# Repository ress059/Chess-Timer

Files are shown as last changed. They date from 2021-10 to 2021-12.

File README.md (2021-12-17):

# Chess-Timer

## Documentation
Bill of Materials, List of Requirements, and Behavioral Test Plans for quality testing.

## Firmware
In progress. Currently prototyping UI using Windows Simulator with LVGL library.

## PCB
Gerber files for manufacturing and PDFs of the board layout.

## Proof of Concept
Video and code to interface [these buttons](https://www.adafruit.com/product/3433) with an Arduino Uno.

## Schematic
PDF of the full schematic.

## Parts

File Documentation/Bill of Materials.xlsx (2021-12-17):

Chess Timer Parts List
 | USB, Programming Header, Battery Charger
 |  | Part | Designator | Part # | Digikey Part # | Quantity | Price Per | Total Price | Product URL (Digikey) | Notes
 | x | USB Mini B Connector | J1 | UX60SC-MB-5ST | UX60SC-MB-5ST-ND | 1 | $0.50 | $0.50 | USB-Mini-B (https://www.digikey.com/en/products/detail/hirose-electric-co-ltd/UX60SC-MB-5ST/3978496) | Already Have. Only for charging
 | x | SWD Connector (2x10) | J2 | TST-110-01-L-D |  | 1 | $3.00 | $3.00 | SWD-Connector (https://www.mouser.com/datasheet/2/527/tst_th-1346016.pdf) | 2x10 Shrouded. Already have. Ridiculous price tag (like $4)
 | o | Resistor (100k) | R1 | CRG0805F100K | A106052TR-ND | 1 | $0.10 | $0.10 | Resistor-100k (https://www.digikey.com/en/products/detail/te-connectivity-passive-product/CRG0805F100K/2380829) | 0805
 | o | Resistor (10k) | R2, R5, R9 (volt regulator EN pin), R13 (BOOT0), R16, R17, R18 | RPC0805JT10K0 | RPC0805JT10K0TR-ND | 7 | $0.10 | $0.70 | Resistor-10k (https://www.digikey.com/en/products/detail/stackpole-electronics-inc/RMCF0805FT10K0/1760676) | 0805. 0.125W
 | o | Slide Switch | S1, S2, S3 | JS102011SCQN | CKN10877TR-ND | 3 | $0.73 | $2.19 | Slide-Switch (https://www.digikey.com/en/products/detail/c-k/JS102011SCQN/3753547) | USB/Programmer Power switch. On-On SPDT for BOOT0 pin on MCU and EN pin on regulator.
 | o | Capacitor - 4.7uF | C1, C2, C6 | CL21A475KAQNNNE | 1276-1244-2-ND | 3 | $0.11 | $0.33 | Capacitor-4.7uF (https://www.digikey.com/en/products/detail/samsung-electro-mechanics/CL21A475KAQNNNE/3886902) | 0805
 | o | Resistor - 470Ω | R3 | ERA-6AED471V | P123851TR-ND | 1 | $0.10 | $0.10 | Resistor-470 (https://www.digikey.com/en/products/detail/panasonic-electronic-components/ERA-6AED471V/9373621) | 0805. 0.125W rating. +/-0.5%
 | o | LED (Green) | LED1, LED2 | APT2012SGC | 754-1131-2-ND | 2 | $0.29 | $0.58 | Green-LED (https://www.digikey.com/en/products/detail/kingbright/APT2012SGC/1747530) | 0805
 | o | Resistor - 5.9kΩ | R4 | ERJ-PB6D5901V | P21107TR-ND | 1 | $0.23 | $0.23 | Resistor-5.9k (https://www.digikey.com/en/products/detail/panasonic-electronic-components/ERJ-PB6D5901V/6213890) | 0805 package. Forward voltage ranges from 2-2.4V.
 | o | MOSFET (P-Channel) | Q1 | MCH3333A-TL-W | MCH3333A-TL-WOSTR-ND | 1 | $0.51 | $0.51 | PFET (https://www.digikey.com/en/products/detail/onsemi/MCH3333A-TL-W/5761742) | Drive Voltage = 1.8V, VGS max = 10V, Id = 2A, Pmax = 0.9W
 | o | LiPo Battery | BT1 | LP603048JK | 1908-1364-ND | 1 | $11.55 | $11.55 | LiPo-Battery (https://www.digikey.com/en/products/detail/jauch-quartz/LP603048JK-PCM-WIRES-70MM/9560986) | 3.7V, 850maH. Standard Charge and Discharge = 0.2C = 170maH Protection Circuit embedded in Battery.
 | x | LiPo Battery Charger | U1 | MCP73831T-2ATI |  | 1 | $0.63 | $0.63 | LiPo-Charger (https://www.digikey.com/en/products/detail/microchip-technology/MCP73831T-2ATI%2FOT/1979803)
 | o | Diode | D1 | S1KB-13-F | S1KB-FDITR-ND | 1 | $0.38 | $0.38 | Diode (https://www.digikey.com/en/products/detail/diodes-incorporated/S1KB-13-F/749978) | 1.1V Forward Voltage, 1A max
 | o | Resistor (0Ω) | R6, R8, R9 | RMCF0805ZT0R00 | RMCF0805ZT0R00TR-ND | 3 | $0.10 | $0.30 | Resistor-0 (https://www.digikey.com/en/products/detail/stackpole-electronics-inc/RMCF0805ZT0R00/1756901) | 0805 package
 | o | Resistor (20Ω) - Charger Testing | R7 | NKN200JT-73-20R | 20.0CECT-ND | 1 | $0.66 | $0.66 | Resistor - 20 (https://www.digikey.com/en/products/detail/yageo/NKN200JT-73-20R/2208391) | 2W power resistor, battery charger testing (TP2).
 | o | Resistor (150Ω) - Charger Testing | R7 | CF14JT150R | CF14JT150RTR-ND | 1 | $0.10 | $0.10 | Resistor - 150 (https://www.digikey.com/en/products/detail/stackpole-electronics-inc/CF14JT150R/1741294) | 0.25W resistor, battery charger testing (TP1).
 | o | Resistor (36kΩ) | R20 | RMCF0805FT36K0 | RMCF0805FT36K0TR-ND | 1 | $0.10 | $0.10 | Resistor - 36k (https://www.digikey.com/en/products/detail/stackpole-electronics-inc/RMCF0805FT36K0/1713062) | 0805. Battery charge STAT pin.
 | Buck-Boost Converter
 |  | Part | Designator | Part # | Digikey Part # | Quantity | Price Per | Total Price | Product URL (Digikey) | Notes
 | x | Buck Boost Converter | U2 | ISL91107IRTNZ-T7A |  | 1 | $2.95 | $2.95 | Buck-Boost-Converter (https://www.mouser.com/ProductDetail/968-ISL91107IRTNZT7A)
 | o | Inductor (1uH) | L1 | NRS5030T1R0NMGJ | 587-3455-2-ND | 1 | $0.33 | $0.33 | Inductor-1uH (https://www.digikey.com/en/products/detail/taiyo-yuden/NRS5030T1R0NMGJ/4157843) | Ferrite, >4.1A saturation, low DCR
 | o | Capacitor (22uF) | C3, C4, C5 | LMK212BBJ226MG-T | 587-5464-2-ND | 3 | $0.27 | $0.81 | Capacitor-22uF (https://www.digikey.com/en/products/detail/taiyo-yuden/LMK212BBJ226MD-T/7675037) | Ceramic 0805, X5R, 10V
 | Microcontroller
 |  | Part | Designator | Part # | Digikey Part # | Quantity | Price Per | Total Price | Product URL (Digikey) | Notes
 | x | MCU | U3 | STM32L100RCT6 |  | 1 | $7.00 | $7.00 | MCU (https://www.digikey.com/en/products/detail/stmicroelectronics/STM32L100RCT6/4357332) | LQFP64 Package, 32-bit, 256kB Flash
 | o | Capacitor (0.1uF)..(100nF) | C7, C8, C9, C10, C12, C13 | 08055C104KAT4A | 478-10836-2-ND | 6 | $0.10 | $0.60 | Capacitor-0.1uF (https://www.digikey.com/en/products/detail/avx-corporation/08055C104KAT4A/6816312) | Ceramic. 0805. X7R. 50V rating. +/-10% capcaitance tolerance.
 | o | Capacitor (1uF) | C11 | CL21B105KAFNNNG | 1276-6469-2-ND | 1 | $0.10 | $0.10 | Capacitor-1uF (https://www.digikey.com/en/products/detail/samsung-electro-mechanics/CL21B105KAFNNNG/3894465) | Ceramic. 0805. X7R. 25V rating. +/- 10% capacitance tolerance.
 | o | Resistor (20kΩ) | R10, R11 ,R12 | CRG0805F20K | A126349TR-ND | 3 | $0.10 | $0.30 | Resistor-20k (https://www.digikey.com/en/products/detail/te-connectivity-passive-product/CRG0805F20K/2380867) | 0805. Battery Voltage monitoring and charger stat pin.
 | x | Reset Button (MCU & LCD) | S4, S5 | TL3342F160QG/TR | EG2531TR-ND | 2 | $0.66 | $1.32 | Reset-Switch (https://www.digikey.com/en/products/detail/e-switch/TL3342F160QG-TR/379004) | Already Have.
 | o | Resistor (330Ω) | R19 | CRGCQ0805J330R | A130131TR-ND | 1 | $0.10 | $0.10 | Resistor-330 (https://www.digikey.com/en/products/detail/te-connectivity-passive-product/CRGCQ0805J330R/8576733) | 0805
 | o | Crystal (16MHz) | XTAL1 | ECS-160-20-3X-TR | XC1776TR-ND | 1 | $0.34 | $0.34 | Crystal-16MHz (https://www.digikey.com/en/products/detail/ecs-inc/ECS-160-20-3X-TR/2676640) | 16MHz, +/-30PPM, 20pF load capacitance, ESR = 50 Ω
 | o | Capacitor (20pF) | C14, C15 | CBR08C200J1GAC | 399-8777-2-ND | 2 | $0.71 | $1.42 | Capacitor-20pF (https://www.digikey.com/en/products/detail/kemet/CBR08C200J1GAC/3481197) | 0805, ceramic, C0G coefficient, meant for high frequency
 | On/Off & Test Points
 |  | Part | Designator | Part # | Digikey Part # | Quantity | Price Per | Total Price | Product URL (Digikey) | Notes
 | x | On/Off Switch | S8 | 471001264143 |  | 1 | $3.49 | $3.49 | On-Off-Switch (https://www.digikey.com/en/products/detail/w%C3%BCrth-elektronik/471001264143/7681921)
 | o | Test Points (Red) | TP1, TP5 | 5010 | 36-5010-ND | 2 | $0.42 | $0.84 | Test Points (Red) (https://www.digikey.com/en/products/detail/keystone-electronics/5010/255332)
 | o | Test Points (Black) | TP2, TP6 | 5011 | 36-5011-ND | 2 | $0.42 | $0.84 | Test Points (Black) (https://www.digikey.com/en/products/detail/keystone-electronics/5011/255333)
 | o | Test Points (White) | TP3, TP4, TP7, TP8, TP9 | 5012 | 36-5012-ND | 5 | $0.42 | $2.10 | Test Points (White) (https://www.digikey.com/en/products/detail/keystone-electronics/5012/255334)
 | Display & UI
 |  | Part | Designator | Part # | Digikey Part # | Quantity | Price Per | Total Price | Product URL (Digikey) | Notes
 | x | LCD Display | U4 | AFY240320B0-2.8N6NTM-R |  | 1 | $15.17 | $15.17 | LCD (https://www.digikey.com/en/products/detail/orient-display/AFY240320B0-2-8N6NTM-R/12089215) | Resistive Touch. Active Area = 57.60 mm H, 43.20 mm W Driver IC = ILI9341V Transmissive Good form factor, and correct driver. However it is relatively small.
 | o | Resistor (110Ω) | R14 ,R15 | ESR10EZPJ111 | RHM110KTR-ND | 2 | $0.10 | $0.20 | Resistor-110 (https://www.digikey.com/en/products/detail/rohm-semiconductor/ESR10EZPJ111/1762753) | 0805. 0.4W Power Dissipation
 | o | Pinheader | J4 | PRPC012DFBN-RC | S2221EC-12-ND | 1 | $0.73 | $0.73 | Pinheader (https://www.digikey.com/en/products/detail/sullins-connector-solutions/PRPC012DFBN-RC/2775482) | 02x12. MCU pinouts, LCD display pinouts.
 | x | Player Pushbuttons | S6, S7 | ADAFRUIT_343X | N/A | 2 | $2.50 | $5.00 | Player-Buttons (https://www.adafruit.com/product/3490)
 | Equipment
 |  | Part | URL | Price
 | o | Fine Solder (0.015in) | Solder (https://www.amazon.com/gp/product/B004X4L076/ref=ewc_pr_img_2?smid=AJ3PYHDIZANTK&psc=1) | $44.00
 | o | Solder Paste (Fine Tip) | Solder-Paste (https://www.amazon.com/gp/product/B006UTCYM2/ref=ewc_pr_img_5?smid=A35TOPIEYAQ7RQ&psc=1) | $20.50
 | o | SMD Tweezers | SMD-Tweezers (https://www.amazon.com/gp/product/B07RNVXXV1/ref=ewc_pr_img_3?smid=A1MA4MZEIPOU47&psc=1) | $8.00
 | o | Solder Wick | Solder-Wick (https://www.amazon.com/gp/product/B0195UVWJ8/ref=ox_sc_act_title_4?smid=ATVPDKIKX0DER&psc=1) | $11.12
 | Additional Tools (University provided)
 | Oscilloscope
 | Heat Gun
 | DC Power Supply
 | Solder (leaded w/ flux core)
 | Soldering Iron
 | Prototyping Wire (22AWG)
 | 3D Printer

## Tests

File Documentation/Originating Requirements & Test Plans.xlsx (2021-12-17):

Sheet: Originating Requirements
Originating Requirements Table for Chess Timer Prototype 1
 |  | Pre-Screen Requirements
 | Index | Originating Requirements | Abstract Function Name
 | OR.1 | No short circuits shall be present in the PCB. | No Short Circuit.
 |  | Battery Protection System (on LiPo)
 | Index | Originating Requirements | Abstract Function Name
 | OR.1 | The Battery Management system shall disconnect the battery from the load if the battery reaches a voltage greater than or equal to 4.28V ±0.025V. | Battery Overvoltage Protection.
 | OR.2 | The Battery Management system shall reconnect the battery to the load with no user input once the battery discharges to a voltage of 4.08V ±0.025V after an Overvoltage Detection. | Battery Overvoltage Release.
 | OR.3 | The Battery Management system shall disconnect the battery from the load if the battery reaches a voltage less than or equal to 3.00V ±0.05V. | Battery Undervoltage Protection.
 | OR.4 | The Battery Management system shall reconnect the battery to the load with no user input once the battery reaches a voltage of 3.00V ±0.05V after an Undervoltage Detection. | Battery Undervoltage Release.
 | OR.5 | The Battery Management system shall disconnect the battery from the load if the load draws between 1.5-3A of current. | Battery Overcurrent Protection.
 | OR.6 | The Battery Management system shall reconnect the battery to the load with no user input once the load draws less than 1.5-3A of current after an Overcurrent detection. | Battery Overcurrent Release.
 | OR.7 | The Battery Management system shall disconnect the battery from the load if the battery is short circuited. | Battery Short Circuit Protection.
 | OR.8 | All exposed components shall withstand "worst-case scenario" load during a short circuit condition. | Components withstanding Short Circuit.
 |  | Battery Charging System
 | Index | Originating Requirements | Abstract Function Name
 | OR.1 | The Battery Charger shall enter a preconditioning phase when the battery is less than 3.0V ± 0.15V. | Charger Preconditioning Phase Detection.
 | OR.2 | During the preconditioning phase, the Battery Charger shall supply 17mA ± 4.25mA of current to the battery. | Charger Preconditioning Phase Current.
 | OR.3 | The Battery Charger shall enter a Constant Current Phase when the battery is greater than 3.0V ± 0.15V. | Charger Constant Current Phase Detection.
 | OR.4 | During the Constant Current Phase, the Battery Charger shall supply 170mA ± 20mA of current to the battery. | Charger Constant Current Phase Current.
 | OR.5 | During charging, the Battery Charger shall enter Shutdown Mode if the supply voltage (VDD) falls within +50mV of VBAT. Shutdown Mode shall only be exited once VDD rises 150mV above VBAT. | Charger Insufficient Supply Voltage Check.
 | OR.6 | The Battery Charger shall enter a Constant Voltage Phase when the battery reaches 4.20V ± 0.032V. | Charger Constant Voltage Phase Detection.
 | OR.7 | During the Constant Voltage Phase, the Battery Charger shall hold the battery at a steady voltage of 4.20V ± 0.032V. | Charger Voltage value during Constant Voltage Phase.
 | OR.8 | The Battery Charger shall complete the Constant Voltage Phase at a termination current within 25mA - 42.5mA (0.03C - 0.05C). | Charger Termination.
 | OR.9 | The Battery Charger shall alert the user when the battery is finished charging. Alert shall stop once the charger is unplugged. | Charging Done Alert.
 |  | Battery Voltage Regulator
 | Index | Originating Requirements | Abstract Function Name
 | OR.1 | The Voltage Regulator shall output 3.3V ± 0.132V when the supply voltage is 1.8V - 5.5V. | Buck-Boost Operation.
 | OR.2 | The Voltage Regulator shall shut down if the supply voltage lowers to 1.60V - 1.795V. | Undervoltage Lockout.
 | OR.3 | After undervoltage lockout, the Voltage Regulator shall resume operation once the supply voltage is above 1.795V. | Operation After Undervoltage Lockout.
 | OR.4 | In buck mode, the Voltage Regulator shall be active if enable pin is HIGH and shut down if enable pin is pulled LOW. | Enable Pin Buck Mode.
 | OR.5 | In boost mode, the Voltage Regulator shall be active if enable pin is HIGH and shut down if enable pin is pulled LOW. | Enable Pin Boost Mode.

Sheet: Test Plans
Test Plans for Chess Timer
 | Pre-Screen Requirements
 | Req. # | Abstract Name | Test # | Test Method | Test Facilities | Entry Condition | Exit Condition | Checklist
 | OR.1 | No Short Circuit. | TP.1 | 1) Set multimeter to measure continuity. 2) Probe multimeter on all power/ground rails of the PCB. | 1) Unpopulated PCB. 2) Multimeter. | PCB is unpopulated, directly from fab house. | Multimeter detects NO continuity on all rails. PCB can now be populated.
 | Battery Protection System 1) DISCONNECT LIPO FROM PROECTION IC.
 | Req. # | Abstract Name | Test # | Test Method | Test Facilities | Entry Condition | Exit Condition | Checklist
 | OR.1 | Battery Overvoltage Protection. | TP.1 | 1) Connect load resistor of 300 Ω to V+ and V- pins (where battery wires originally were) 2) Set power supply at 4.0V 3) Connect bench power supply to B+ and B- pins (where battery tabs were originally). 4) Slowly raise power supply to 4.28V. 5) If battery successfully disconnects (power supply reads 0A of current), slowly lower power supply to 4.08V to see if battery successfully reconnects. 6) Repeat 5 times. | 1) Bench power supply. 2) Battery Protection Circuit. 3) 300 Ω resistor. | Bench power supply at 4.0V and load resistor hooked up to circuit. Measurable current going through the load. | Battery disconnected from the load at 4.28V ±0.025V., then reconnected at 4.08V ±0.025V.
 | OR.2 | Battery Overvoltage Release.
 | OR.3 | Battery Undervoltage Protection. | TP.2 | 1) Connect load resistor of 300 Ω to V+ and V- pins (where battery wires originally were) 2) Set power supply to 4.2V. 3) Connect bench power supply to B+ and B- pins (where battery tabs were originally). 4) Slowly lower power supply to 3.0V. 5) If battery successfully disconnects (power supply reads 0A of current), slowly raise power supply to 3.1V to see if battery successfully reconnects. 6) Repeat 5 times. | 1) Bench power supply. 2) Battery Protection Circuit. 3) 300 Ω resistor. | Bench power supply at 4.2V and load resistor hooked up to circuit. Measurable current going through the load. | Battery disconnected from the load at 3.00V ±0.05V, then reconnected at 3.1V or less.
 | OR.4 | Battery Undervoltage Release.
 | OR.5 | Battery Overcurrent Protection. | TP.3 | 1) Connect load resistor to V+ and V- pins (where battery wires originally were) 2) Load Resistor Configuration: Lowest: ESR of 2.5Ω. (1.28 - 1.68A). Medium: ESR of 2Ω (1.6 - 2.1A). Higher: ESR of 1.5Ω. (2.1 - 2.8A). Highest: ESR of 1.1Ω (2.9A - 3.8A). **Note: current calculations based on voltages of 3.2 - 4.2V. 3) Set power supply to 3.2V. 4) Connect bench power supply to B+ and B- pins (where battery tabs were originally). 5) Slowly raise power supply until battery disconnects, or voltage reaches 4.2V. 6) Record supply voltage when circuit disconnects. 7) If no disconnnection happens, use next highest resistor network. 8) Lower the voltage again until battery is automatically reconnected. 9) Repeat 5 times. Average the voltage and current calculation to get overcurrent trigger threshold. | 1) Bench power supply. 2) Battery Protection Circuit. 3) ESR of 2.5Ω Power Resistor. 4) ESR of 2Ω Power Resistor. 5) ESR of 1.5Ω Power Resistor. 6) ESR of 1.1Ω Power Resistor. 7) 12 gauge wire. | Bench power supply at 3.2V and load resistor network hooked up to circuit. | Battery disconnected from the load at overcurrent detection threshold, then automatically reconnected once current is less than threshold.
 | OR.6 | Battery Overcurrent Release.
 | OR.7 | Battery Short Circuit Protection. | TP.4 | 1) ONLY CONDUCT TEST IF BATTERY OVERCURRENT PROTECTION TEST WAS SUCCESSFUL. 2) Solder wires to V+ and V- pins (where battery wires originally were) with rocker switch. 3) Connect bench power supply to B+ and B- pins (where battery tabs were originally). 4) Turn on power supply to 3.0V 5) Turn on rocker switch. 6) Verify if short circuit protection occurs. 7) If it does, repeat test in 0.3V increments (3.0V, 3.3V, 3.6V, etc) up to 4.3V. | 1) Bench power supply. 2) Battery Protection Circuit. 3) 12 gauge wire. 4) Rocker switch. | Bench power supply and rocker switch connected to protection circuitry. Rocker switch turned on to initiate short circuit. | Short circuit detection occurs and disconnects power supply.
 | OR.8 | Components Withstanding Short Circuit.
 | Battery Charging System
 | FOR ALL BATTERY CHARGING TESTING, UNPLUG 5V RAIL (JLINK PROGRAMMER), DISCONNECT R6 (0 OHM GOING INTO SOURCE OF MOSFET), and DISCONNECT R8 (0 OHM GOING INTO VREG OF VOLTAGE REGULATOR).
 | Req. # | Abstract Name | Test # | Test Method | Test Facilities | Entry Condition | Exit Condition | Checklist
 | OR.1 | Charger Preconditioning Phase Detection | TP.1 | 1) Connect Power Supply to TP1 and TP2 test points. 2) Assuming precondition current of 17mA, set R7 to 150Ω (so VBAT = 2.55V). 3) Connect multimeter to TP3 and TP4 to measure current through R7. 4) Set power supply to 5V, 300mA. 5) Verify measured current is 17mA ± 4.25mA. | 1) Power Supply 2) Multimeter 3) 150Ω resistor. With > 0.05W dissipation. | Multimeter connected to TP3 and TP4. Power supply @ 5V, 300mA | 17mA ± 4.25mA is measured through R7.
 | OR.2 | Charger Preconditioning Phase Current
 | OR.3 | Charger Constant Current Phase Detection. | TP.2 | 1) Connect Power Supply to TP1 and TP2 test points. 2) Assuming precondition current of 170mA, set R7 to 20Ω (so VBAT = 3.4V). 3) Connect multimeter to TP3 and TP4 to measure current through R7. 4) Set power supply to 5V, 300mA. 5) Verify measured current is 170mA ± 20mA. | 1) Power Supply 2) Multimeter 3) 20Ω resistor. With > 0.75W dissipation. | Multimeter connected to TP3 and TP4. Power supply @ 5V, 300mA | 170mA ± 20mA is measured through R7.
 | OR.4 | Charger Constant Current Phase Current.
 | OR.5 | Charger Insufficient Supply Voltage Check. | TP.3 | 1) Connect Power Supply to TP1 and TP2 test points. 2) Set R7 to 20Ω (so VBAT = 3.4V) and charger in constant current phase. 3) Connect multimeter to TP3 and TP4 to measure current through R7. 4) Set power supply to 5V, 300mA. 5) Verify current is read on multimeter. 6) Lower power supply to 3.3V. 0 current should be going through multimeter. 7) Raise power supply to 3.7V. Current should now be going through multimeter. | 1) Power Supply 2) Multimeter 3) 20Ω resistor. With > 0.75W dissipation. | Multimeter connected to TP3 and TP4. Power supply @ 3.3V, 300mA | No current going through multimeter. Power supply raised to 3.7V and current now going through multimeter.
 | ALL PREVIOUS MUST TESTS MUST PASS BEFORE ENTERING CONDUCTING THIS TEST. INSERT LIPO INTO CIRCUIT FOR THIS TEST. DISCONNECT R6 (0 OHM GOING INTO SOURCE OF MOSFET Q1), DISCONNECT R7 (VARIABLE TESTING RESISTOR), DISCONNECT R8 (0OHM GOING INTO VREG OF VOLTAGE REGULATOR), DISCONNECT R10 (CHARGE ENABLE RESISTOR), DISCONNECT POWER SUPPLY FROM TP1 AND TP2, DISCONNECT MULTIMETER FROM TP3 AND TP4. SET R3 = 470 OHMS.
 | OR.9 | Charging Done Alert. | TP.4 | 1) Flip S1 USB charging setting. 2) Connect USB power supply. 3) Charge LiPo. WAIT IN THE ROOM FOR THE ENTIRE CHARGING CYCLE, COULD TAKE FEW HOURS. 4) Verify status LED (LED1) turns on. | 1) LiPo. 2) USB power. | LiPo charging safely through battery charger. | Status LED is turned on, indicating the end of a charging cycle.
 | Battery Voltage Regulator
 | DISCONNECT LIPO FROM CIRCUIT! DISCONNECT USB/5V CHARGING RAIL (JLINK/USB), DISCONNECT R8 (0 OHM RESISTOR CONNECTING VREG TO REGULATOR),
 | Req. # | Abstract Name | Test # | Test Method | Test Facilities | Entry Condition | Exit Condition | Checklist
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

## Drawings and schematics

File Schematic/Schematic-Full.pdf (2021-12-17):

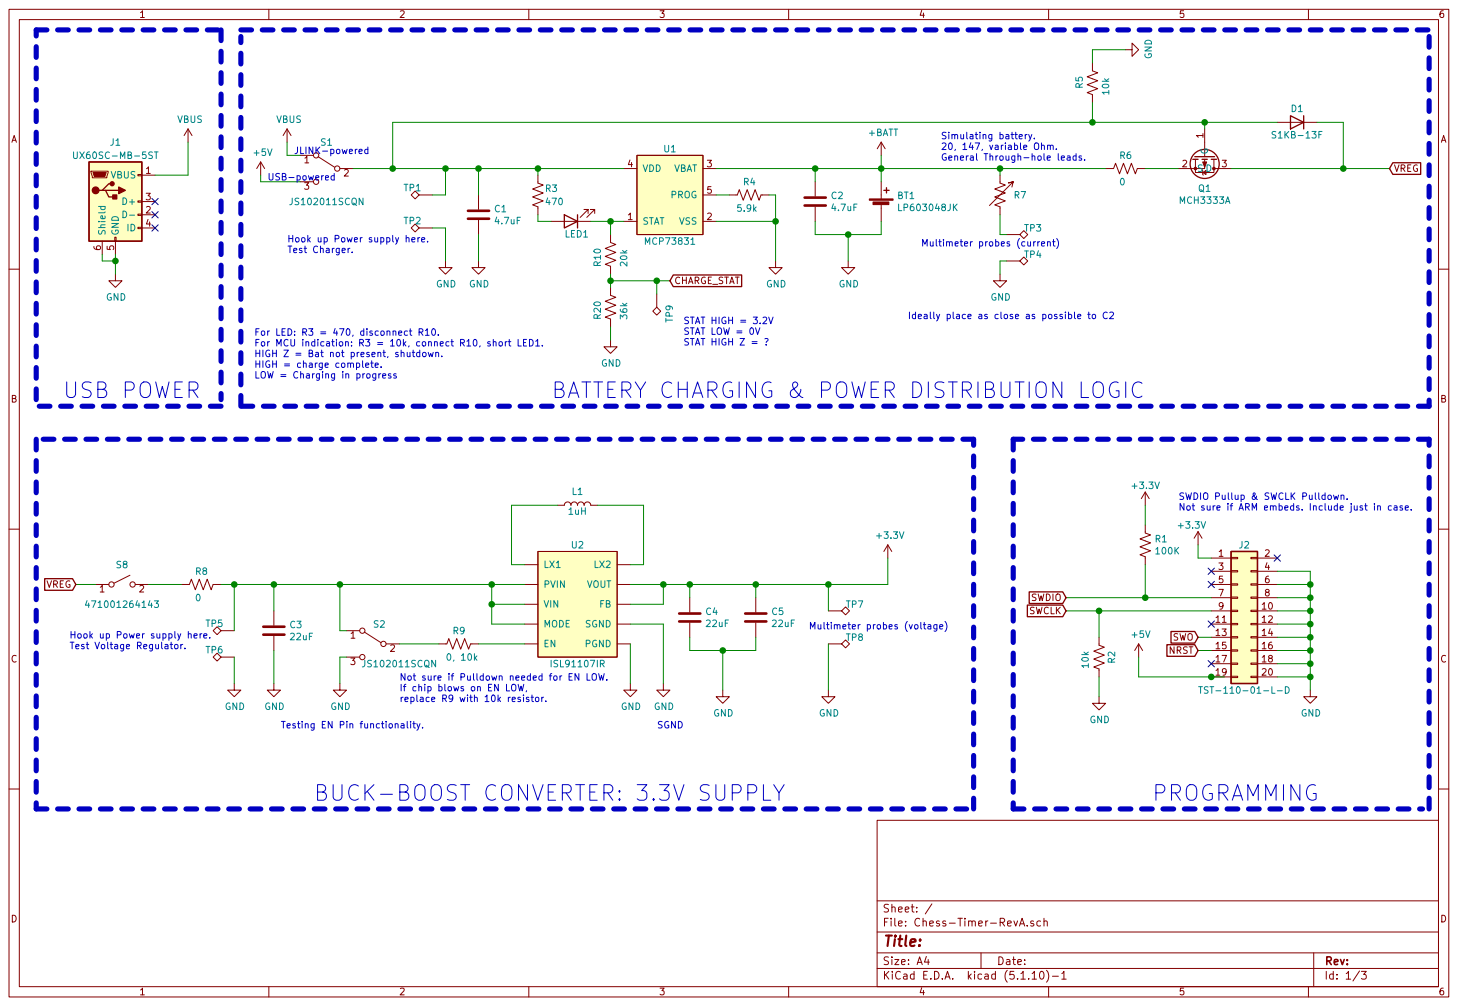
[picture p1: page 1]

File: Chess-Timer-RevA-pg2.sch R6

Simulating battery. 20, 147, variable Ohm. General Through-hole leads.

Hook up Power supply here.
Test Charger.

Ideally place as close as possible to C2 SGND
STAT LOW = 0V
STAT HIGH Z = ?

For LED: R3 = 470, disconnect R10. For MCU indication: R3 = 10k, connect R10, short LED1. HIGH Z = Bat not present, shutdown.

BATTERY CHARGING & POWER DISTRIBUTION LOGIC

SWDIO Pullup & SWCLK Pulldown.
Not sure if ARM embeds. Include just in case.

Test Voltage Regulator.

If chip blows on EN LOW,

Testing EN Pin functionality.

BUCK-BOOST CONVERTER: 3.3V SUPPLY

Id: 1/3 Title: File: Chess-Timer-RevA.sch Sheet: /

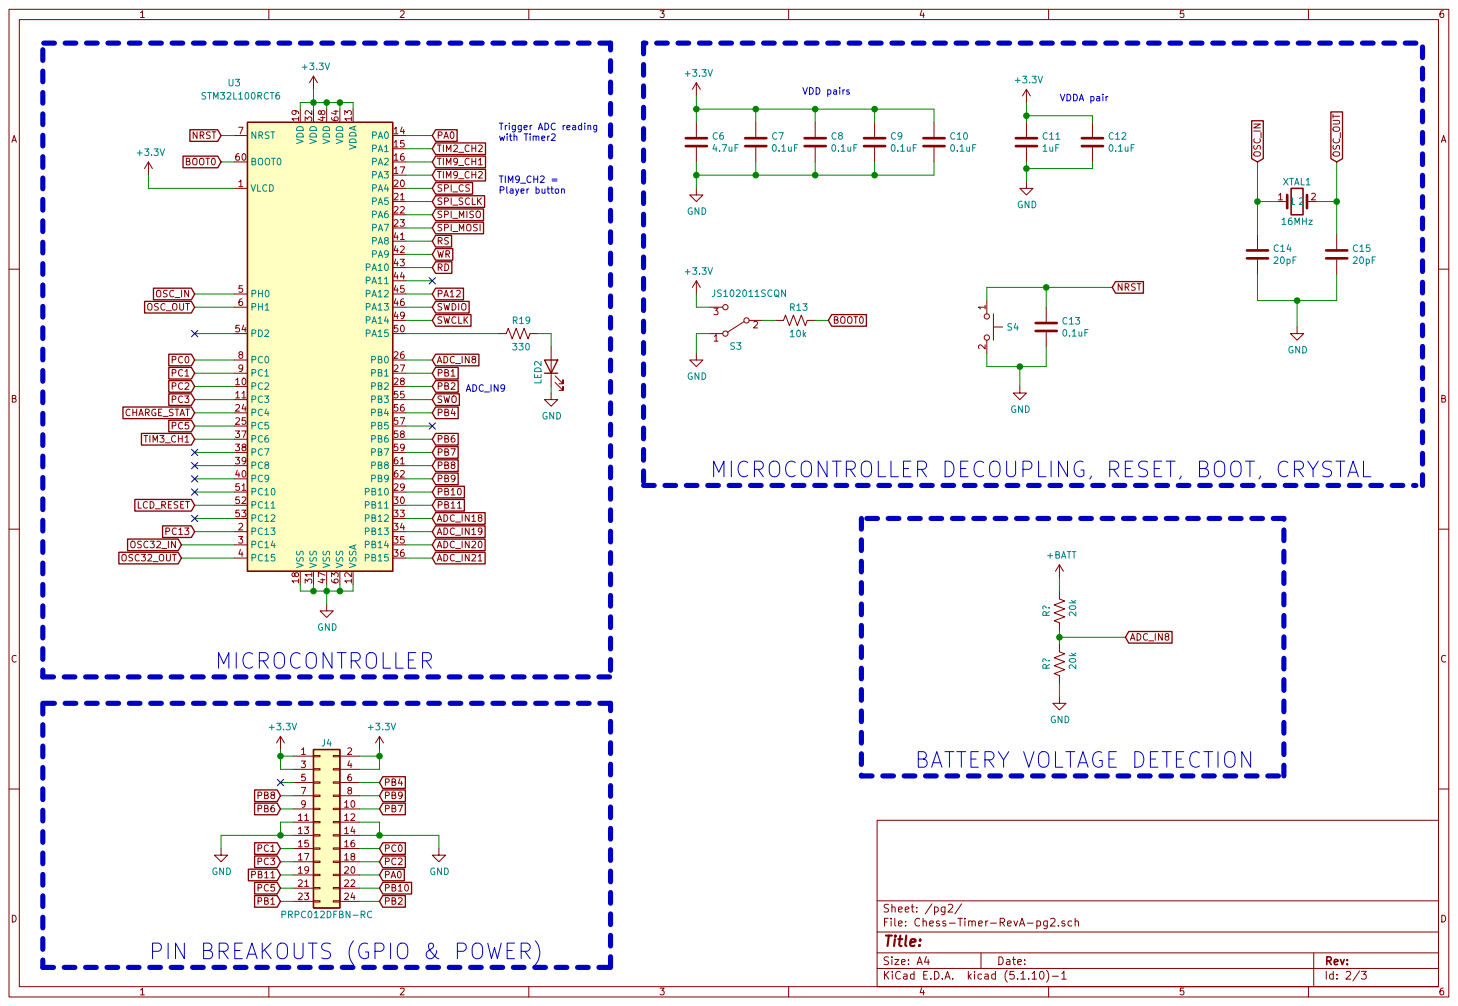
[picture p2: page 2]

Trigger ADC reading with Timer2 ADC_IN9TIM9_CH2 = Player button

MICROCONTROLLER DECOUPLING, RESET, BOOT, CRYSTAL

13 | 14
15 | 16

Sheet: /pg2/
File: Chess-Timer-RevA-pg2.sch
Id: 2/3 Title:

PIN BREAKOUTS (GPIO & POWER)

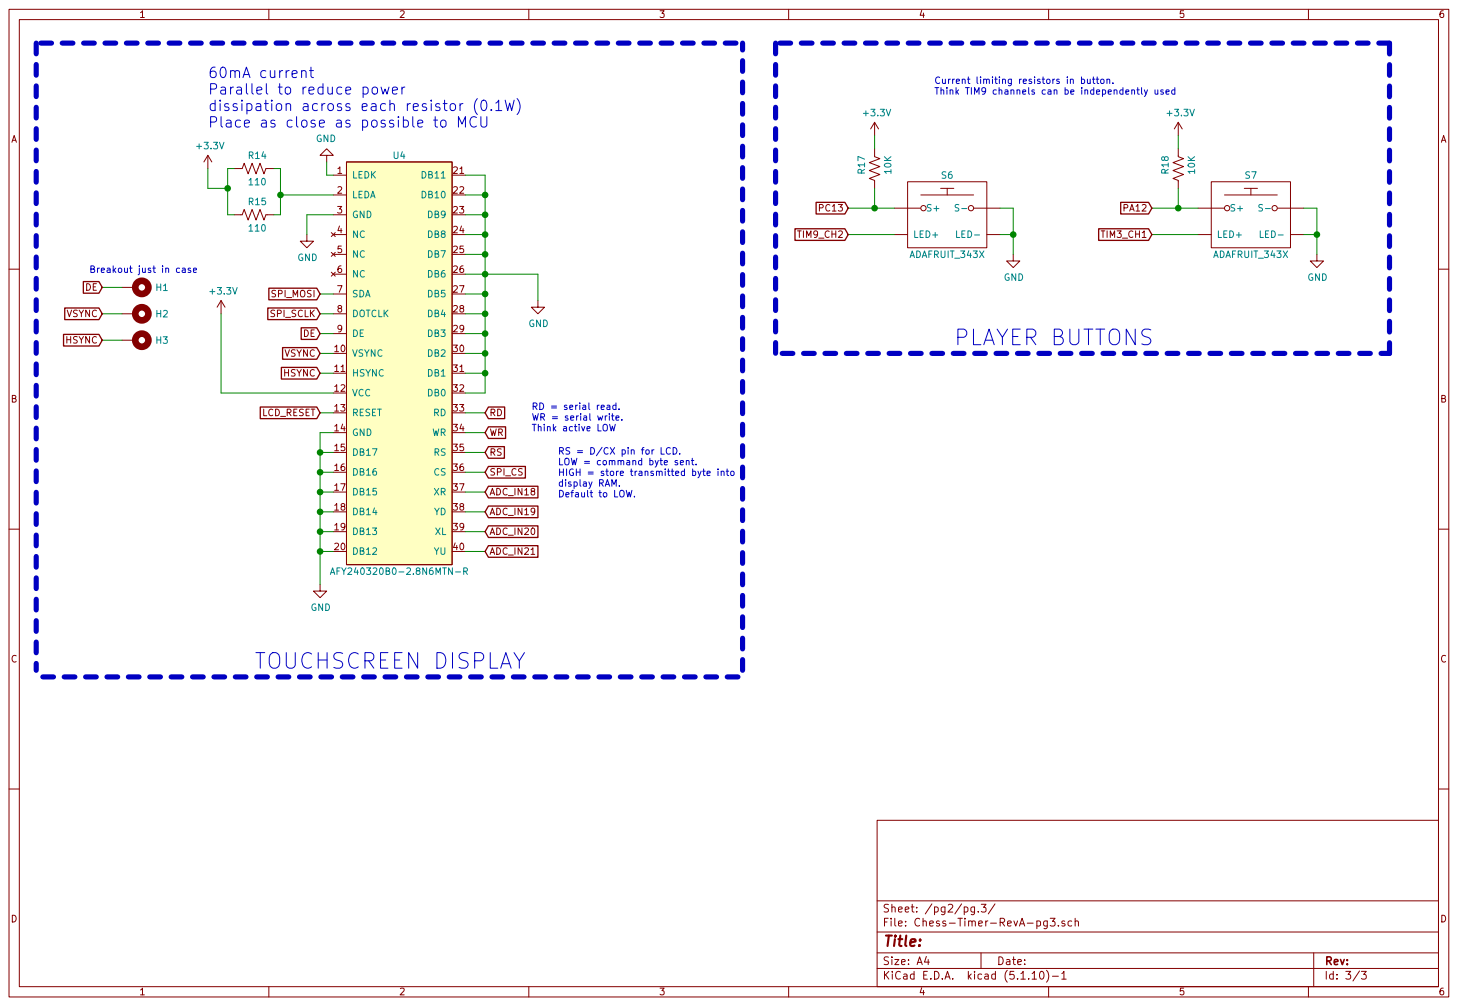
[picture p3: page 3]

display RAM. Default to LOW. 60mA current
Parallel to reduce power
dissipation across each resistor (0.1W)
Place as close as possible to MCU

Current limiting resistors in button.

Think TIM9 channels can be independently used RD = serial read. WR = serial write. Think active LOW

SPI_MOSI Breakout just in case

RS = D/CX pin for LCD.
LOW = command byte sent.
ADC_IN21 ADC_IN20 ADC_IN19 ADC_IN18 SPI_CS

HIGH = store transmitted byte into

Sheet: /pg2/pg.3/
File: Chess-Timer-RevA-pg3.sch
Id: 3/3 Title:

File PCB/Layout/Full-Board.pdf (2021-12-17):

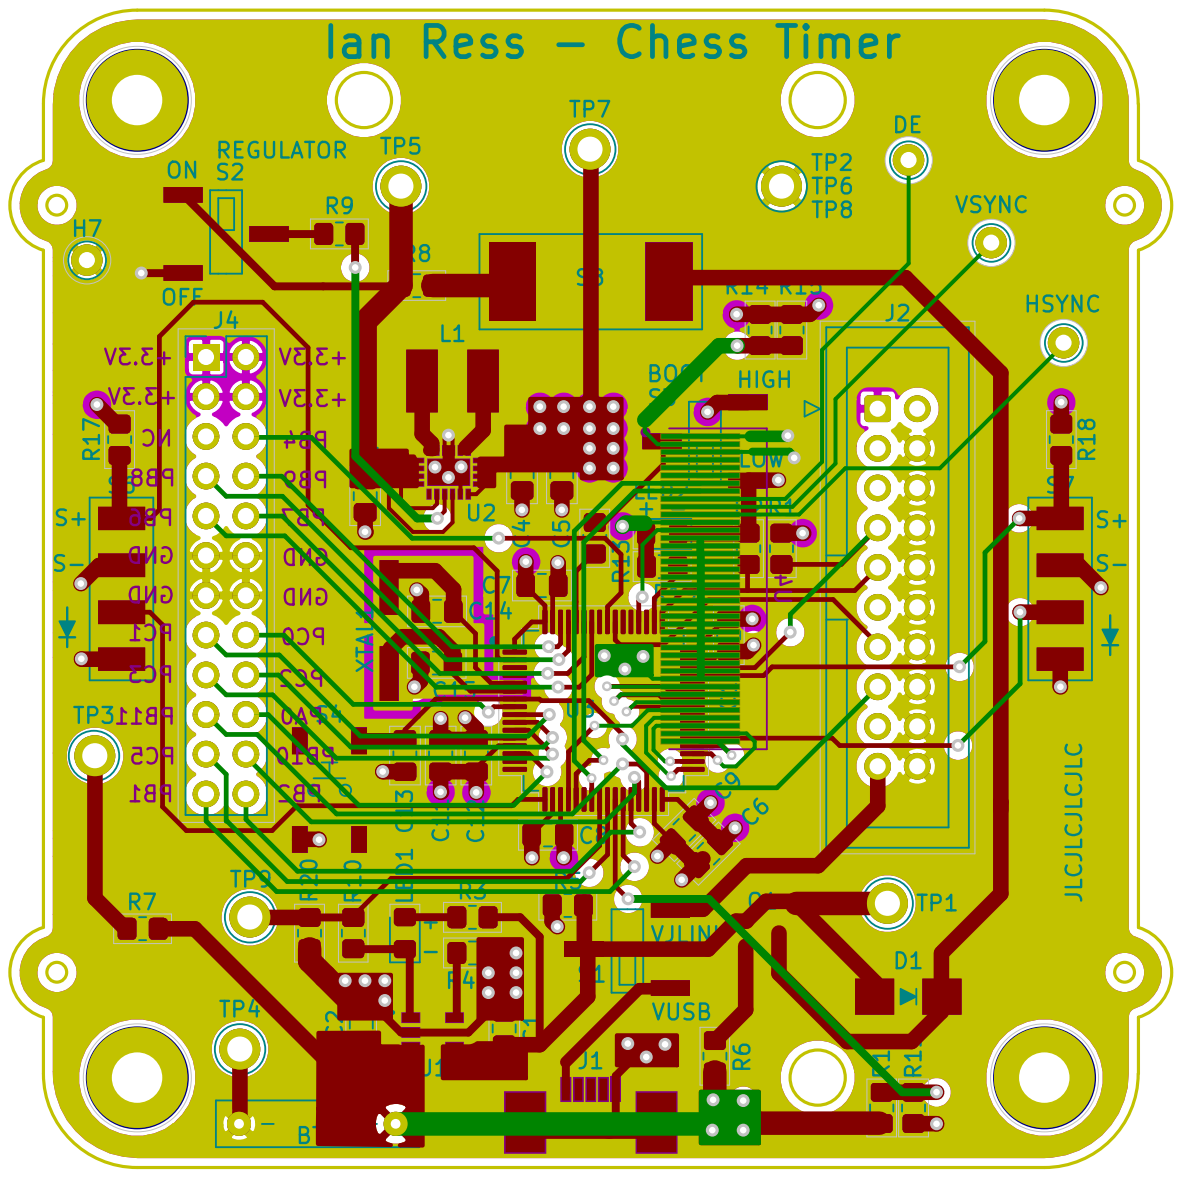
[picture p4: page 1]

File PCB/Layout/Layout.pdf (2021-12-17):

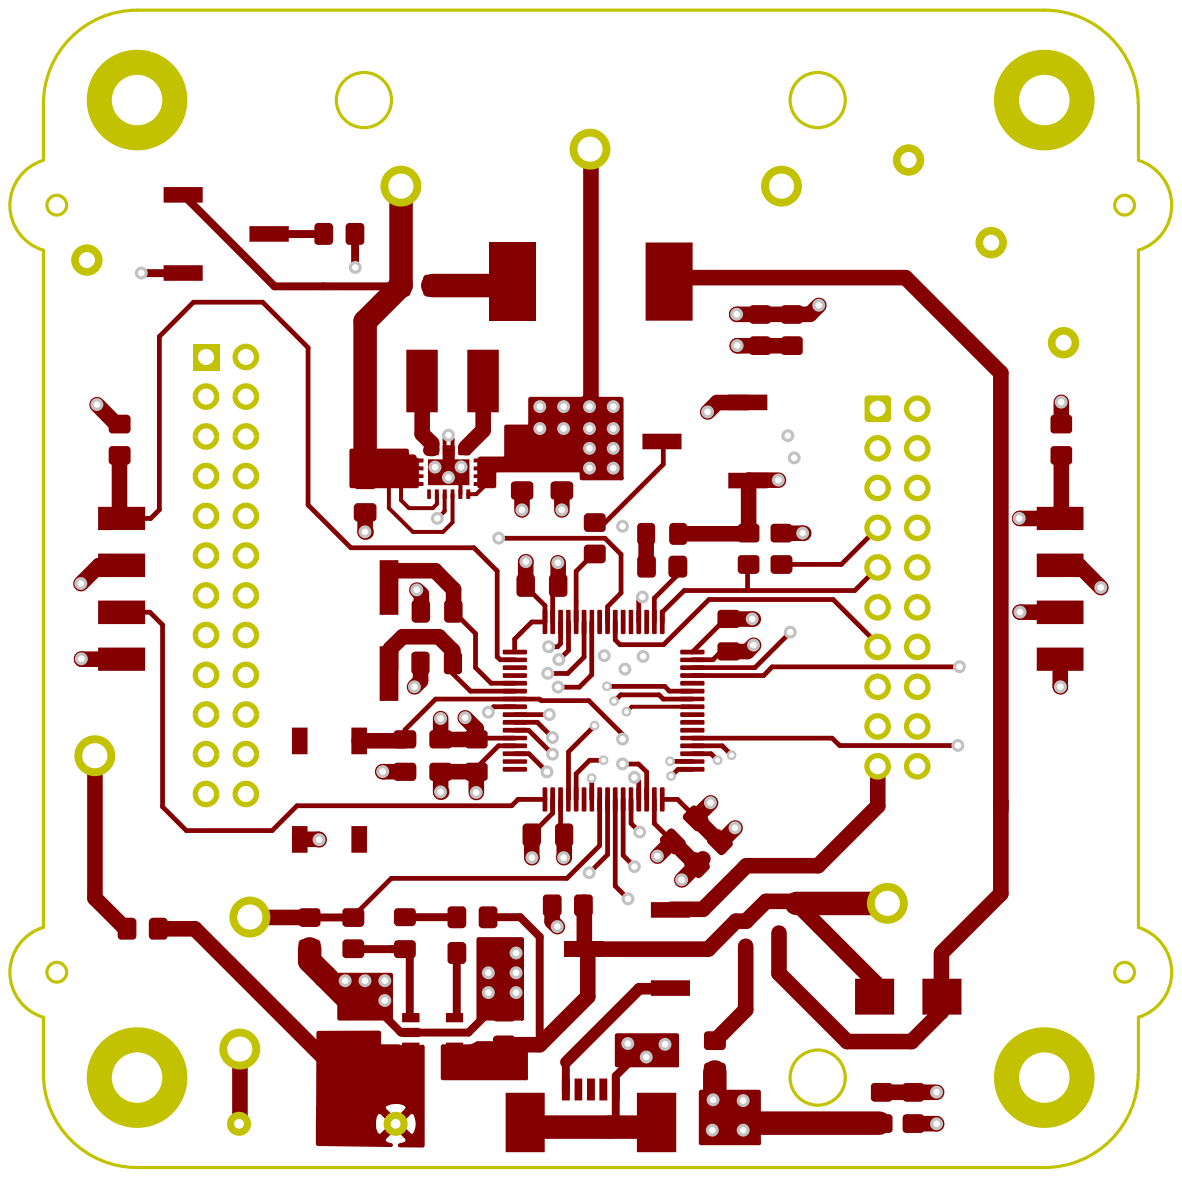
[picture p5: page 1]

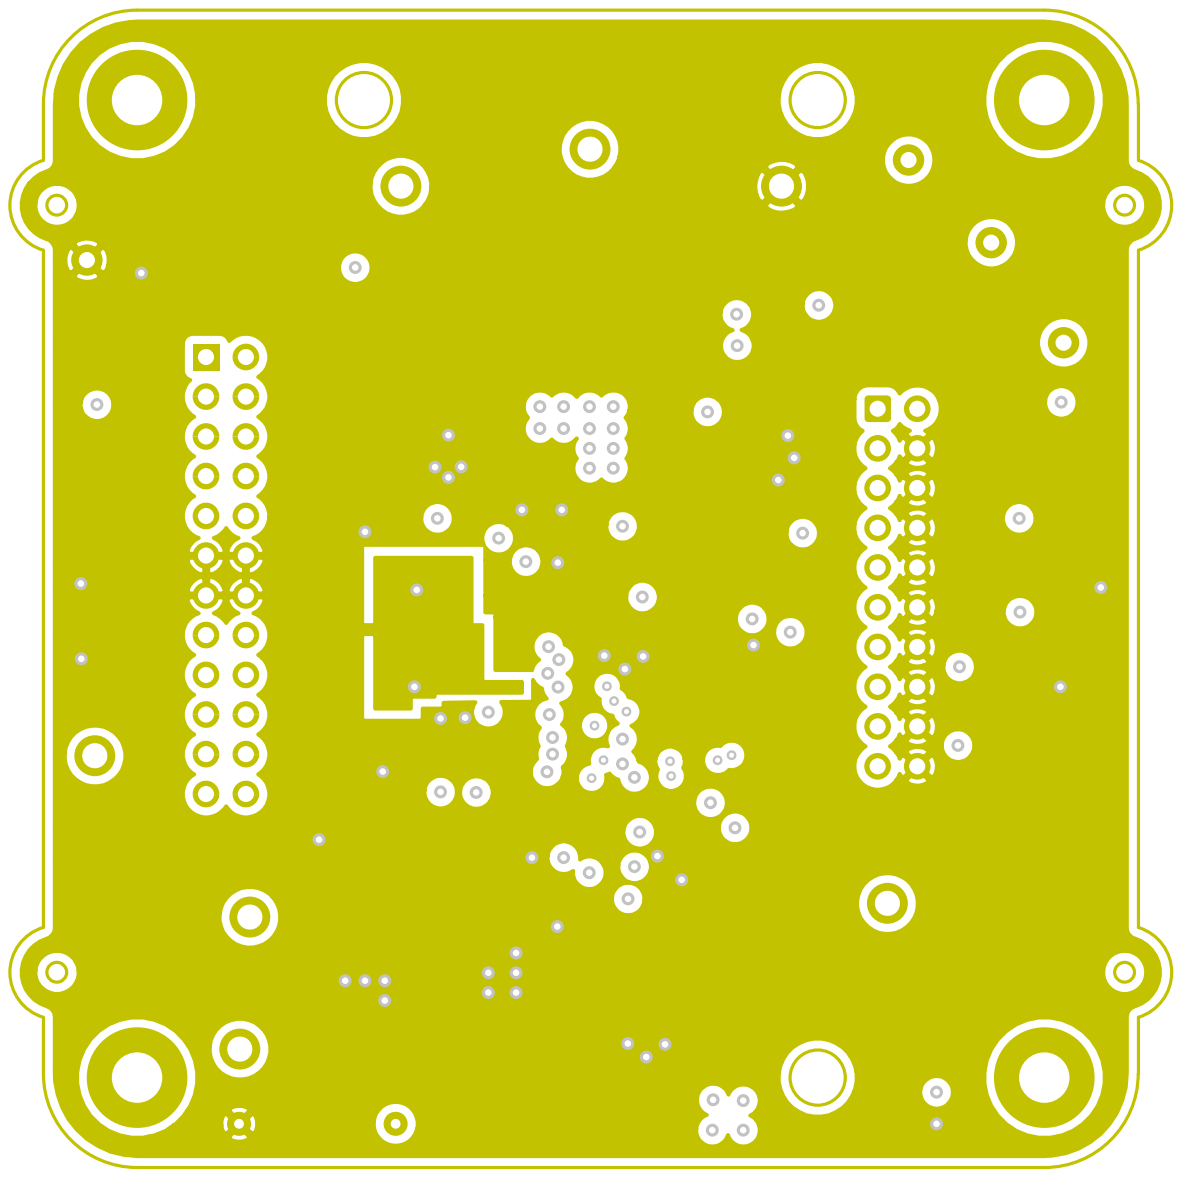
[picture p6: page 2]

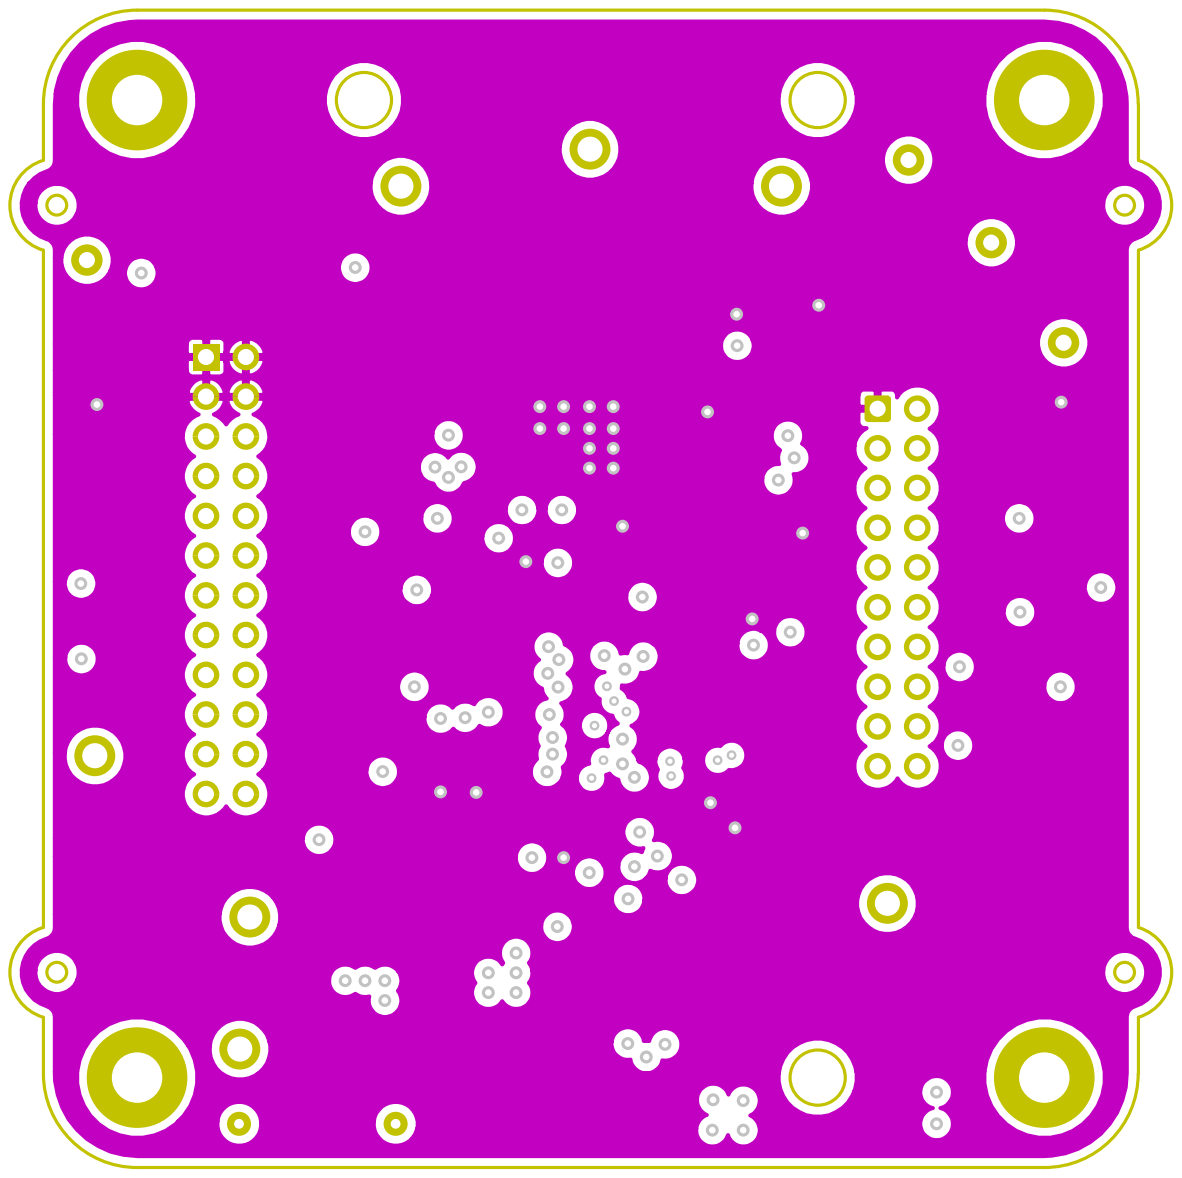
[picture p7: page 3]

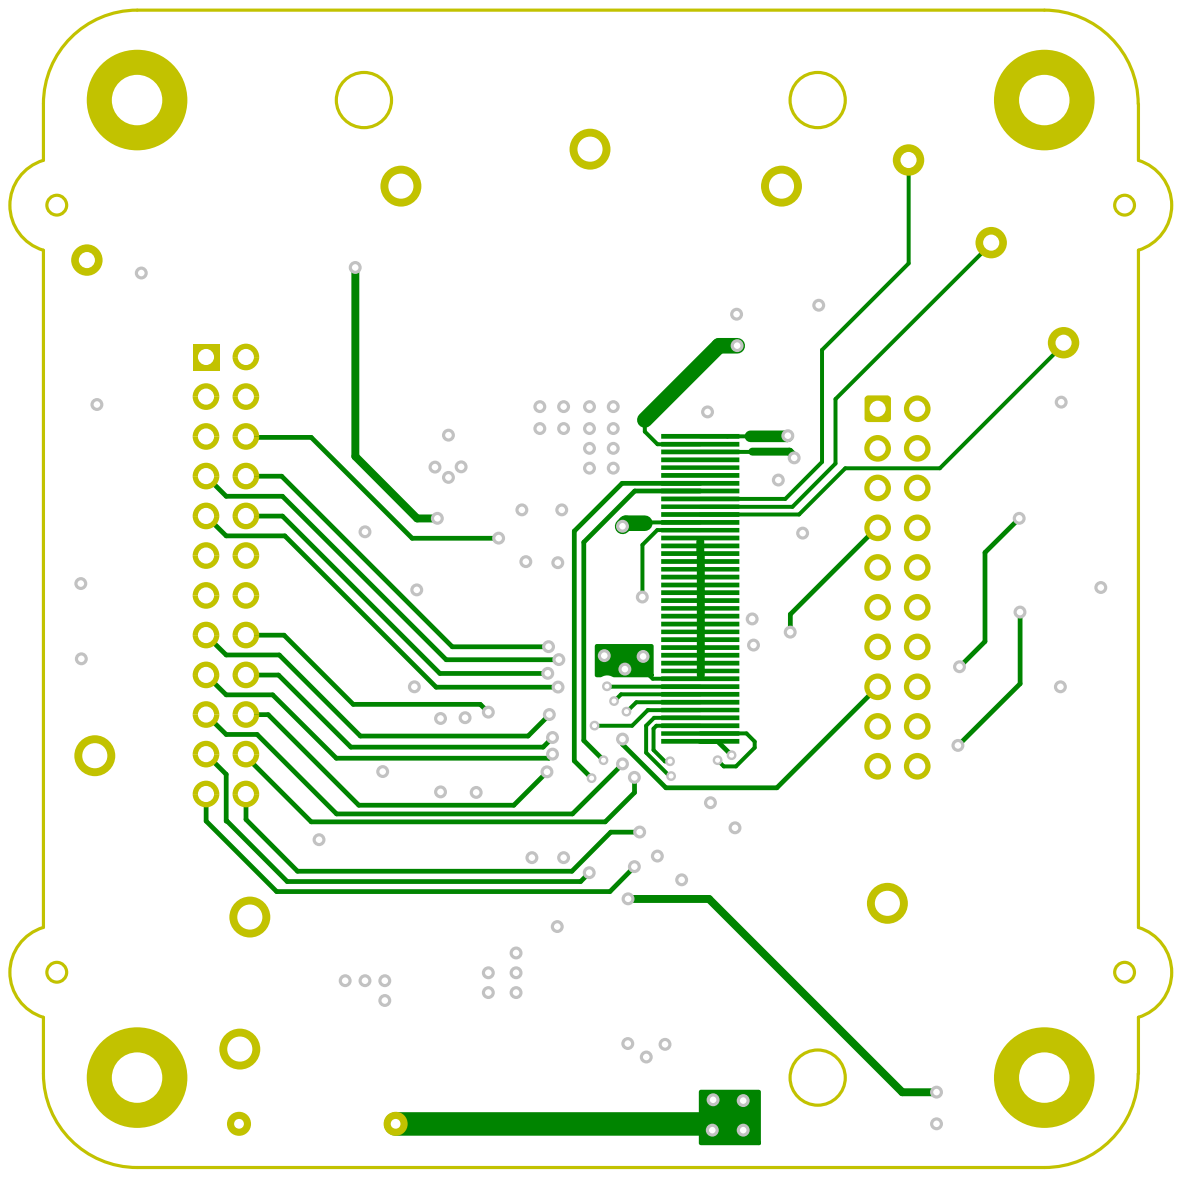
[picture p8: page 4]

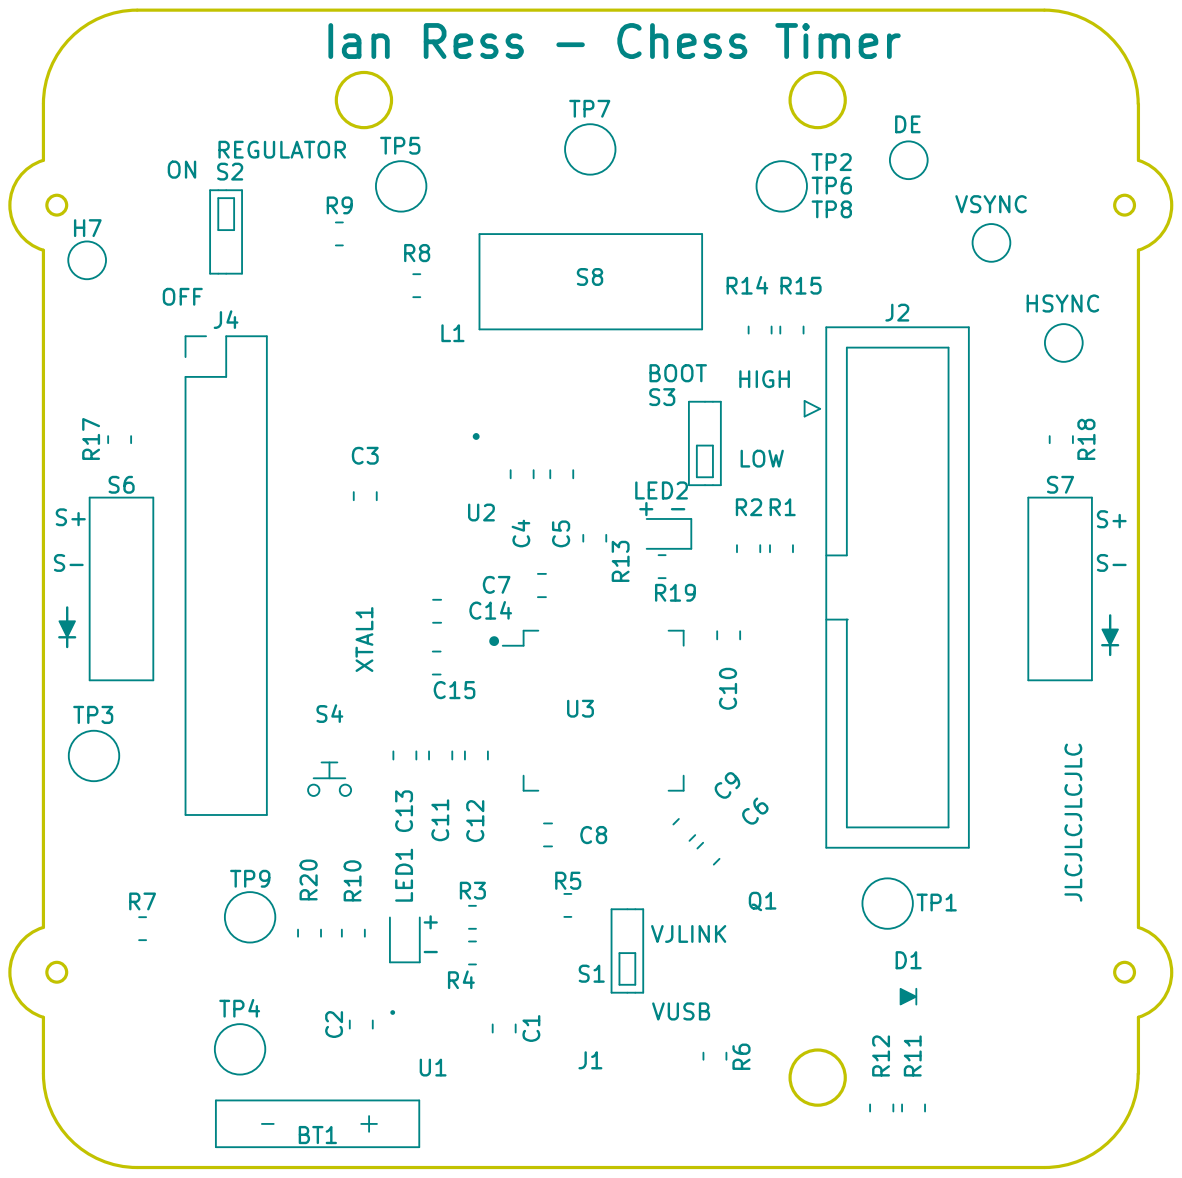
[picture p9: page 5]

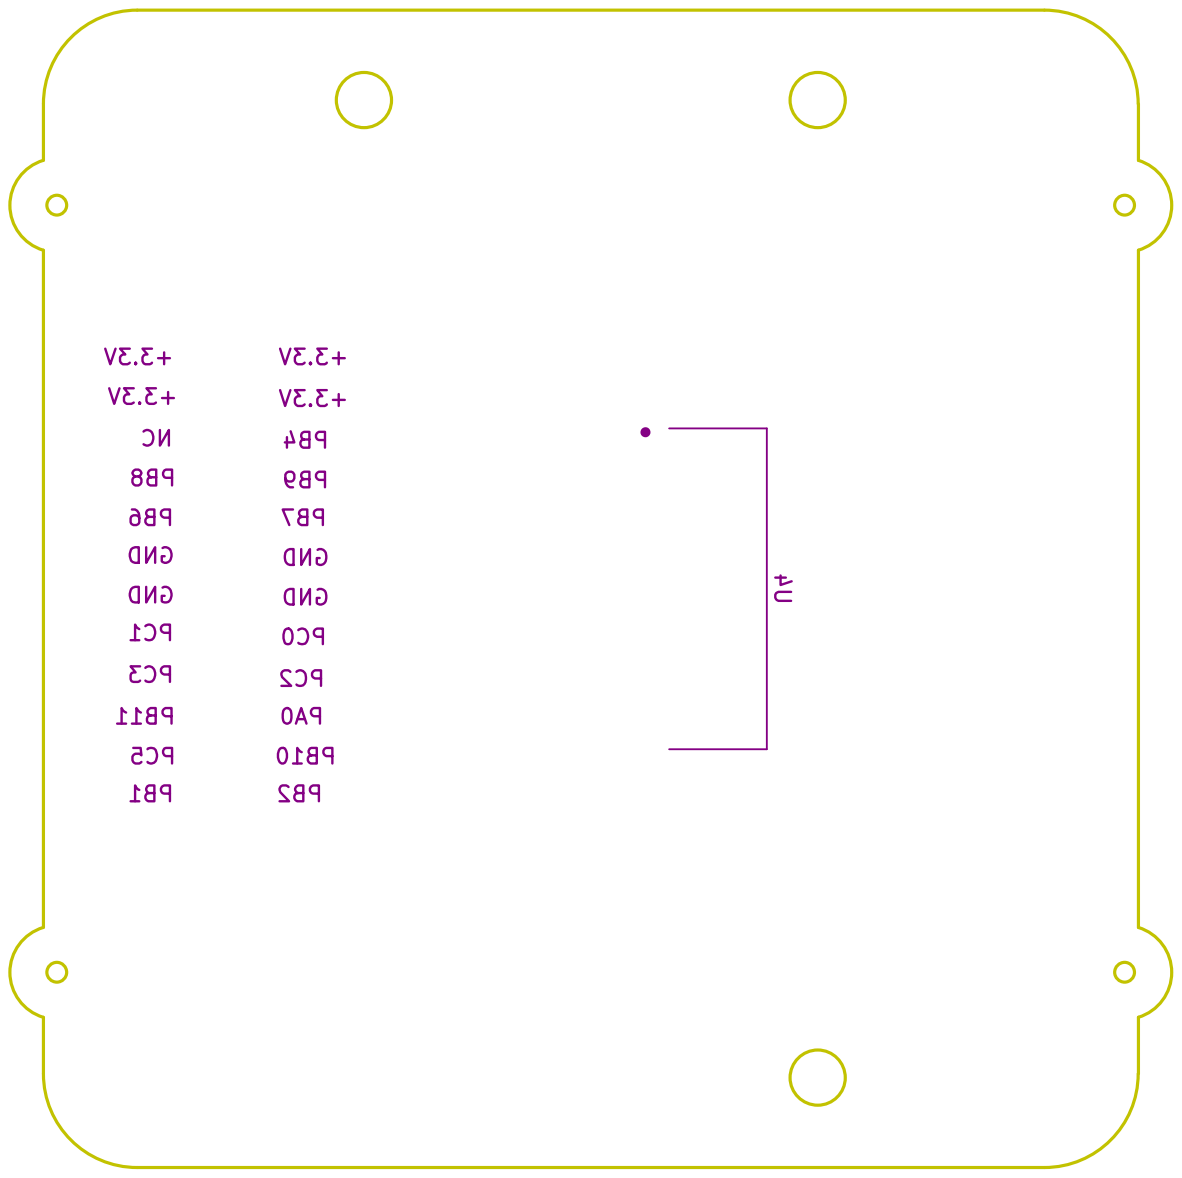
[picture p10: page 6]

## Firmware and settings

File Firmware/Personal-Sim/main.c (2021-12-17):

/*********************
 *      INCLUDES
 *********************/
#include <stdlib.h>
#include <unistd.h>

#include "lvgl/lvgl.h"
#include "lv_drivers/win_drv.h"
#include <windows.h>

/*********************
 *      DEFINES
 *********************/

/**********************
 *      TYPEDEFS
 **********************/

/**********************
 *  STATIC PROTOTYPES
 **********************/
static void hal_init(void);
static int tick_thread(void *data);

/**********************
 *  STATIC VARIABLES
 **********************/

/**********************
 *      MACROS
 **********************/

/**********************
 *   GLOBAL FUNCTIONS
 **********************/
#if WIN32
int APIENTRY WinMain(HINSTANCE hInstance, HINSTANCE hPrevInstance, LPSTR szCmdLine, int nCmdShow)
#else
int main(int argc, char** argv)
#endif // WIN32
{
    /*Initialize LittlevGL*/
    lv_init();

    /*Initialize the HAL for LittlevGL*/
    hal_init();

    /*Check the themes too*/
    lv_disp_set_default(lv_windows_disp);

    /*Run the v7 demo*/
    chess_timer_ui();

#if WIN32
    while(!lv_win_exit_flag) {
#else
    while(1) {
#endif // WIN32
        /* Periodically call the lv_task handler.
         * It could be done in a timer interrupt or an OS task too.*/
        lv_task_handler();
        usleep(1000);       /*Just to let the system breath*/
    }
    return 0;
}

/**********************
 *   STATIC FUNCTIONS
 **********************/

/**
 * Initialize the Hardware Abstraction Layer (HAL) for the Littlev graphics library
 */
static void hal_init(void)
{
#if !WIN32
    /* Add a display
     * Use the 'monitor' driver which creates window on PC's monitor to simulate a display*/
    monitor_init();
    lv_disp_drv_t disp_drv;
    lv_disp_drv_init(&disp_drv);            /*Basic initialization*/
    disp_drv.disp_flush = monitor_flush;
    disp_drv.disp_fill = monitor_fill;
    disp_drv.disp_map = monitor_map;
    lv_disp_drv_register(&disp_drv);

    /* Add the mouse (or touchpad) as input device
     * Use the 'mouse' driver which reads the PC's mouse*/
    mouse_init();
    lv_indev_drv_t indev_drv;
    lv_indev_drv_init(&indev_drv);          /*Basic initialization*/
    indev_drv.type = LV_INDEV_TYPE_POINTER;
    indev_drv.read = mouse_read;         /*This function will be called periodically (by the library) to get the mouse position and state*/
    lv_indev_drv_register(&indev_drv);

    /* Tick init.
     * You have to call 'lv_tick_handler()' in every milliseconds
     * Create an SDL thread to do this*/
    SDL_CreateThread(tick_thread, "tick", NULL);
#else
    /* This sets up some timers to handle everything. */
    windrv_init();
#endif
}
#if !WIN32
/**
 * A task to measure the elapsed time for LittlevGL
 * @param data unused
 * @return never return
 */
static int tick_thread(void *data)
{
    while(1) {
        lv_tick_inc(1);
        SDL_Delay(1);   /*Sleep for 1 millisecond*/
    }

    return 0;
}
#endif

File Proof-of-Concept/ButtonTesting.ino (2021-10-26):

///////////////// PROGRAM DESCRIPTION /////////////////
/* This program tests the ADAFRUIT 343X Buttons
 * 
 * 1) The green button LED will originally be turned on.
 * 2) The green button LED will only be turned off once it is pressed.
 * 3) Once pressed, blue button LED will then turn on.
 * 4) The blue button LED will only be turned off once it is pressed.
 * 5) Green LED illuminated again and cycle repeats indefinately.
 */

/////////////// CONSTS ////////////////
const uint8_t greenbuttonpin = 2;
const uint8_t greenledpin = 13;
const uint8_t bluebuttonpin = 4;
const uint8_t blueledpin = 10;

////////////// TYPEDEFS ///////////////
typedef enum{
  blue,
  green
} buttontracker;

buttontracker led; 

///////////// GLOBAL PROTOTYPES ///////////
void test(buttontracker a);

void setup() {
  pinMode(greenbuttonpin, INPUT);
  pinMode(greenledpin, OUTPUT);
  pinMode(bluebuttonpin, INPUT);
  pinMode(blueledpin, OUTPUT);
  
  digitalWrite(greenledpin, HIGH);
  led = green;
}

void loop() {
  test(led);
}

void test(buttontracker a){
  while (a == green){
    if (digitalRead(greenbuttonpin)==0){ //pressed
      digitalWrite(greenledpin, LOW);
      digitalWrite(blueledpin, HIGH);
      a = blue;
    }
  }

  while (a == blue){
    if (digitalRead(bluebuttonpin)==0){ //pressed
      digitalWrite(blueledpin, LOW);
      digitalWrite(greenledpin, HIGH);
      a = green;
    }
  }
}

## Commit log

2021-12-17 Create Schematic
2021-12-17 Create PCB
2021-12-17 Create gerber
2021-12-17 Create bom
